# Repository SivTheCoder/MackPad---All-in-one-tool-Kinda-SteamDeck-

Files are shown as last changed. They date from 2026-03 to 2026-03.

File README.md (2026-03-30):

# MackPad — All-in-One Macro Controller  
### By Sivansh Gupta  

---

##  Overview  
**MackPad** is a compact, high-efficiency macropad built to maximize functionality within minimal hardware constraints. Powered by the **Seeeduino XIAO ESP32-S3**, it leverages nearly every available GPIO pin to deliver a rich, customizable user experience.

Designed for **developers, creators, and productivity enthusiasts**, MackPad combines tactile input, visual feedback, and programmable workflows into a single portable device.

---

##  Project Showcase  

### Full Assembly (PCB + Case)
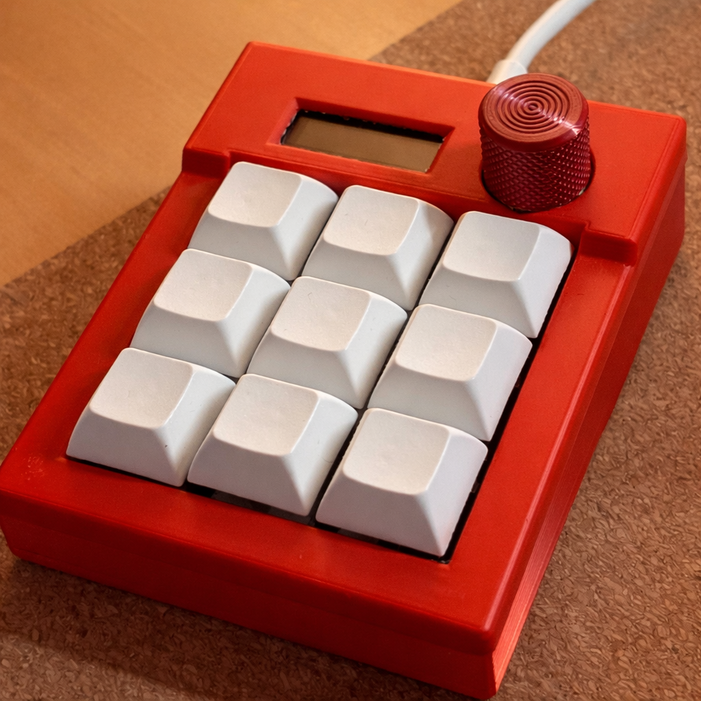
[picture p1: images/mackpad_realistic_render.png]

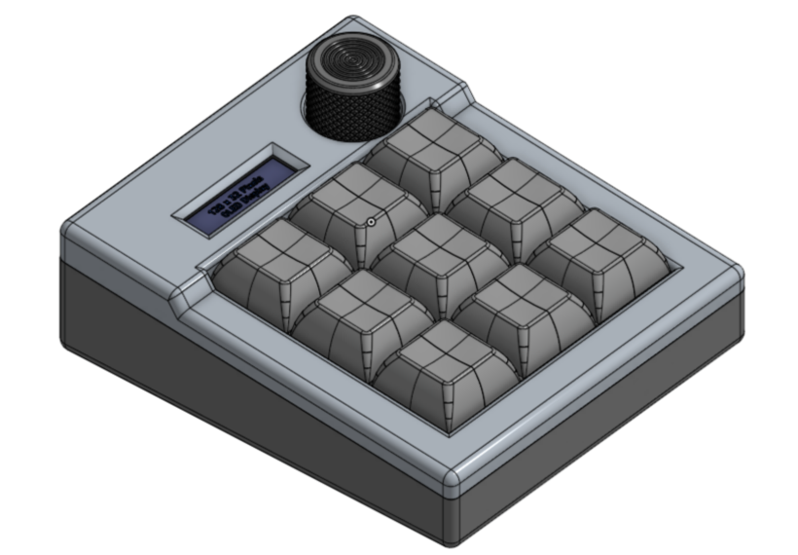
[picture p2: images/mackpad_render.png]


### PCB Design  
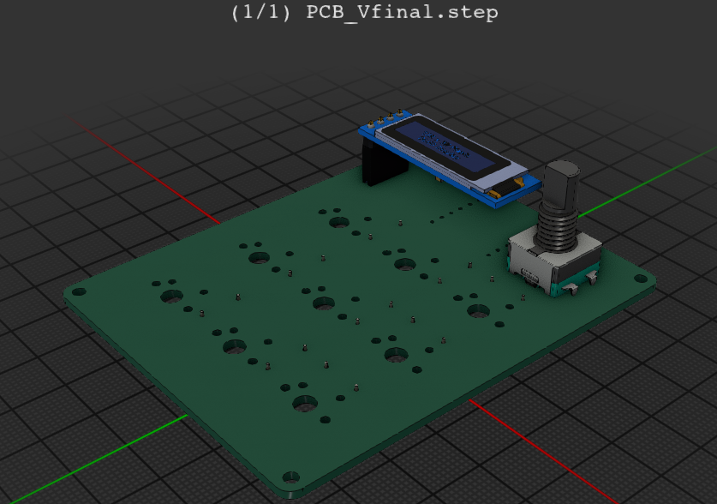
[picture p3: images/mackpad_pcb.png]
PCB


### Different Components  
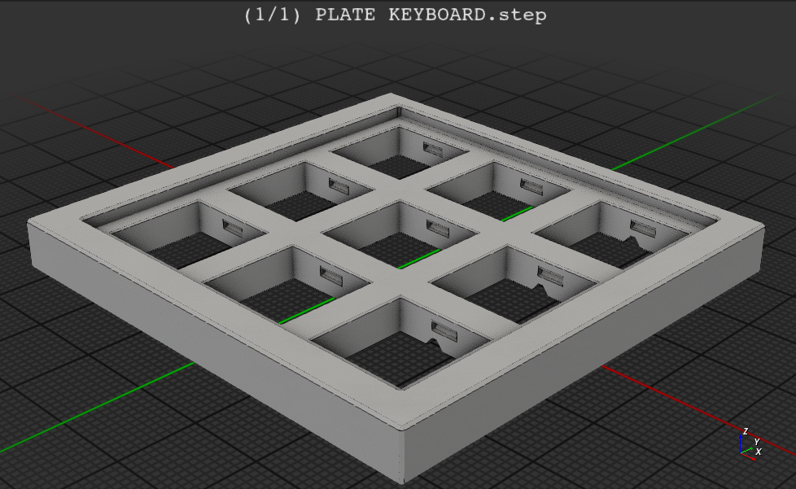
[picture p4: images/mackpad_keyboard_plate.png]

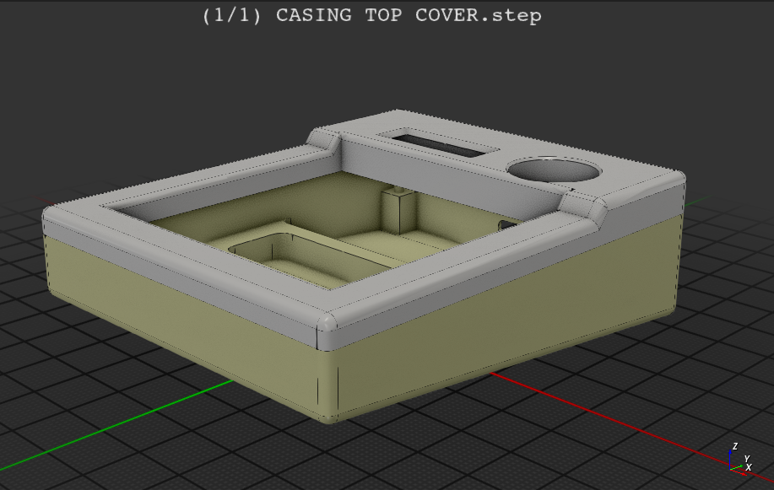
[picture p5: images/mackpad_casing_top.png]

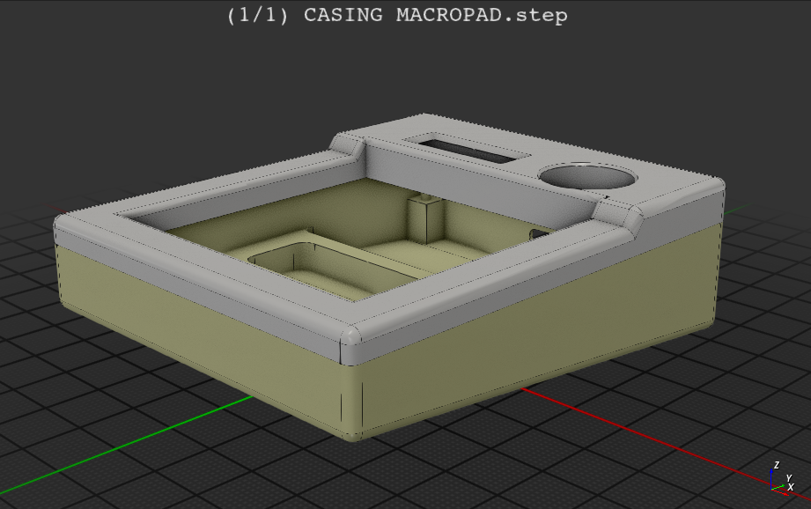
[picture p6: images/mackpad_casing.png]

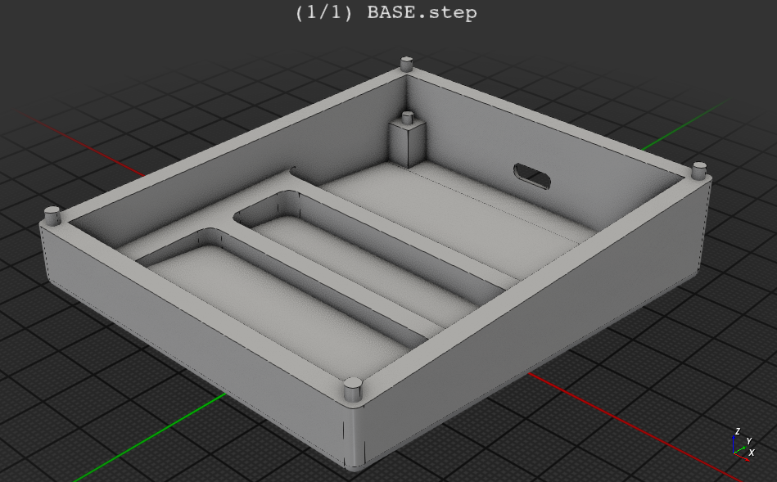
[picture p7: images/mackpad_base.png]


##  Key Features  

- 3×3 NKRO Mechanical Keypad  
- Rotary Encoder with Push Functionality  
- 0.91" OLED Display (Real-time UI Feedback)  
- Neopixel RGB Backlighting  
- Hot-swappable Switch Support  
- Fully Programmable via KMK Firmware  
- Compact and Efficient Embedded Design  

---

##  Motivation  

MackPad began as a simple rotary encoder-based volume controller. It evolved into a fully-featured macropad focused on:

- Speeding up workflows  
- Reducing repetitive actions  
- Providing intuitive visual feedback  
- Maximizing functionality within hardware constraints  

---

##  Hardware Architecture  

- **Microcontroller:** Seeeduino XIAO ESP32-S3  
- **Input System:** 3×3 matrix with diodes (NKRO support)  
- **Rotary Encoder:** Analog-based custom decoding  
- **Display:** SSD1306 OLED (I2C, 128×32)  
- **Lighting:** WS2812 Neopixels  
- **Switches:** MX-style (hot-swappable with Kailh sockets)  

---

##  Firmware  

- Built using **KMK Firmware (CircuitPython)**  
- Features include:  
  - Custom keymaps and macros  
  - OLED UI (layer status, icons, system info)  
  - Rotary encoder multi-function control  
  - Neopixel-based visual feedback  
  - Custom key objects and advanced macro handling  

---

##  Usage  

### Setup  

1. Flash CircuitPython firmware onto the XIAO ESP32-S3  
2. Copy the following to the device:  
   - `code.py`  
   - Required KMK libraries  
   - Display assets (icons/images)  
3. Reboot the device  

---

### Customization  

All customization is handled inside `code.py`:

- Key mappings  
- Macros and shortcuts  
- RGB lighting behavior  
- OLED display output  

---

##  Bill of Materials (BOM)  

| Qty | Component | Notes | USD | INR |
|-----|---|---|---|---|
| 1 | Seeeduino XIAO ESP32-S3 | Microcontroller | $6.00 | ₹500  |
| 9 | MX-style switches | Mechanical switches | $4.50 | ₹375  |
| 9 | 1N4148 diodes | Matrix diodes | $0.90 | ₹75 |
| 1 | SSD1306 OLED (0.91", 128x32) | Display | $3.00 | ₹250  |
| 9 | DSA keycaps | Keycaps | $5.00 | ₹400  |
| 1 | Female header (1x4) | Display mount | $0.50 | ₹40 |
| 1 | EC11 rotary encoder | Input control | $1.50 | ₹120  |
| 3 | Resistors (10k, 47k, 100k) | Voltage divider | $0.30 | ₹30 |
| 9 | Kailh hot-swap sockets | Switch mounting | $6.00 | ₹500  |

### Estimated Total  
- **USD:** ~$27.70  
- **INR:** ~₹2,290  

*Prices may vary depending on supplier.*

---

##  Future Improvements  

### Advanced RGB System  
- Per-key RGB lighting  
- Layer-based color profiles  
- Reactive lighting effects  

### Touch Input Integration  
- Capacitive touch gestures  
- Swipe and tap controls  
- Hybrid input system  

### Wireless Capability  
- Bluetooth connectivity  
- Battery-powered operation  

### Enhanced UI  
- Animated OLED interface  
- Menu-based navigation  
- Dynamic macro previews  

---

##  Project Highlights  

- Efficient use of limited GPIO resources  
- Custom analog decoding for rotary encoder  
- Integration of hardware + firmware + UI design  
- Fully functional productivity tool  

---

### Custom Python-Based Companion Software (Steam Deck Integration)

- Development of a dedicated Python-based companion application designed to run alongside MackPad  
- Enables deep integration with devices like the Steam Deck or PC environments for advanced task execution  
- Supports bidirectional communication between MackPad and the host system (e.g., via Bluetooth/Wi-Fi/USB)  
- Allows dynamic macro triggering based on system context (active app, game state, or workflow)  
- Provides a customizable UI/dashboard for real-time control, monitoring, and macro management  
- Transforms MackPad from a standalone macropad into a hybrid hardware-software control system  
- Unlocks capabilities beyond traditional hackpads, including system-level automation, scripting, and adaptive workflows  

---

##  License  

This project is open-source and available under the MIT License.

---

##  Acknowledgements  

- KMK Firmware Community  
- Good people of Hack Club

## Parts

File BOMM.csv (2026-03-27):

Qty | Item | Notes
1 | SEEEDUINO XIAO ESP32-S3 | Microcontroller board
9 | MX-style switches | 5-pin preferred
9 | 1N4148 through-hole diodes | For switch matrix
1 | SSD1306 128x32 OLED 0.91" | I2C display
9 | Blank DSA keycaps
1 | 1x4 2.54mm female header | For raising display height
1 | EC11 rotary encoder
1 | 10kΩ metal film resistor | Part of voltage divider
1 | 47kΩ metal film resistor | Voltage divider
1 | 100kΩ metal film resistor | Voltage divider
9 | Kailh MX hot-swap sockets | For hot-swappable switches

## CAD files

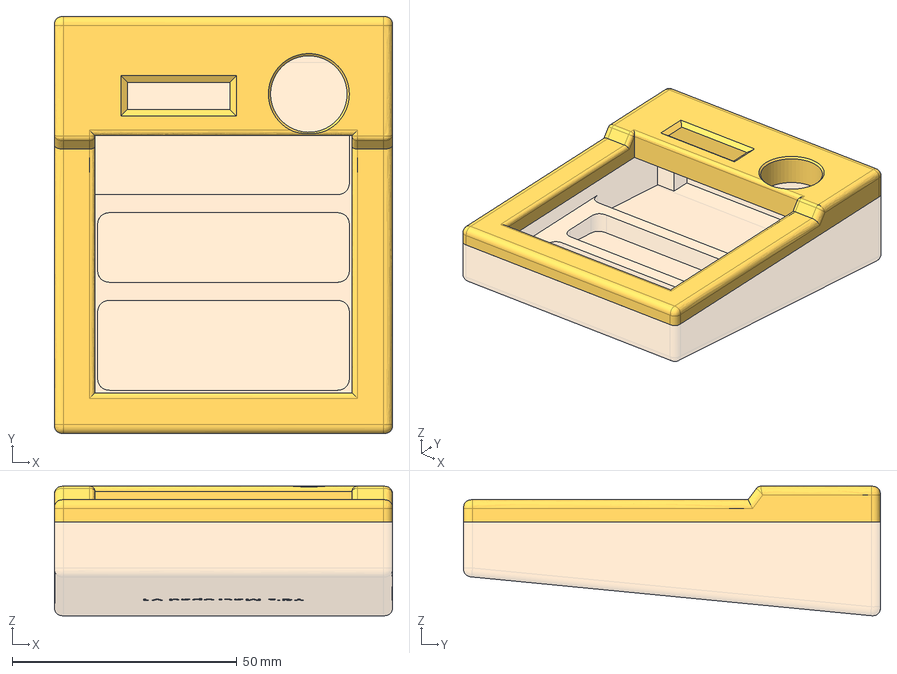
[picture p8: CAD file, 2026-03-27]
CAD Files_Vfinal/CASING TOP COVER.step
75.2 x 92.7 x 28.8 mm

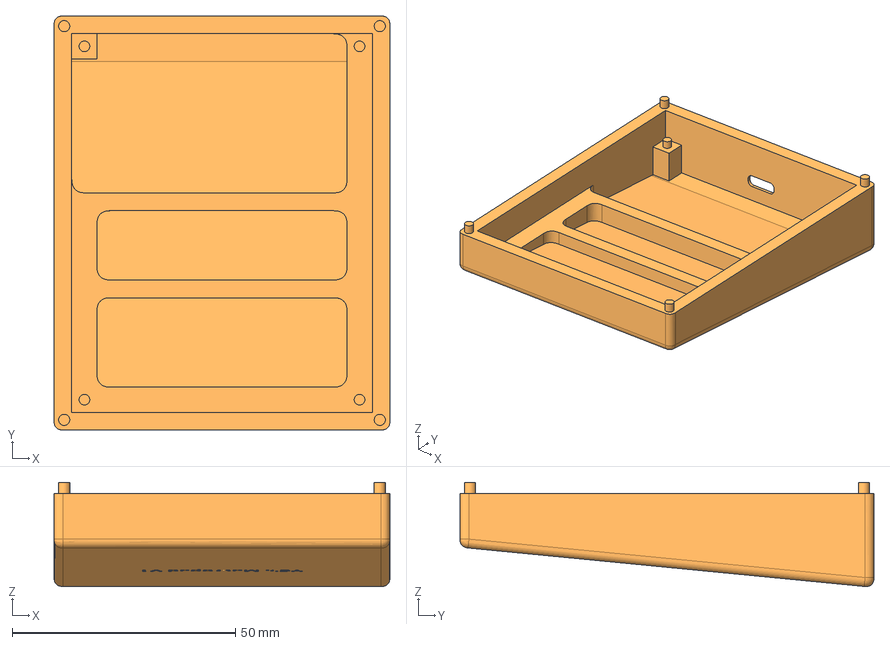
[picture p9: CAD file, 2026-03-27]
CAD Files_Vfinal/BASE.step
75.2 x 92.7 x 23.3 mm

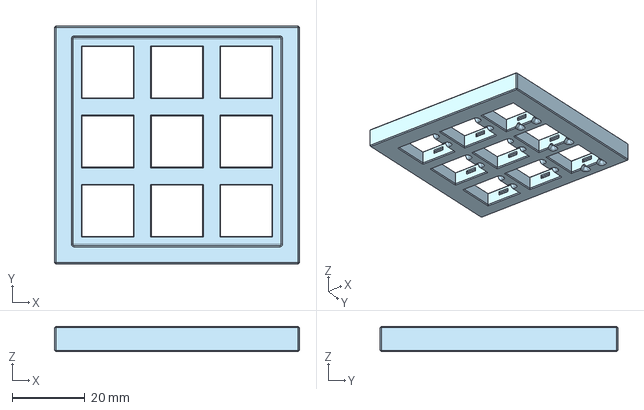
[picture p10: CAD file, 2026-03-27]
CAD Files_Vfinal/PLATE KEYBOARD.step
67.4 x 65.4 x 7.00 mm

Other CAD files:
CAD Files_Vfinal/CASING MACROPAD.step

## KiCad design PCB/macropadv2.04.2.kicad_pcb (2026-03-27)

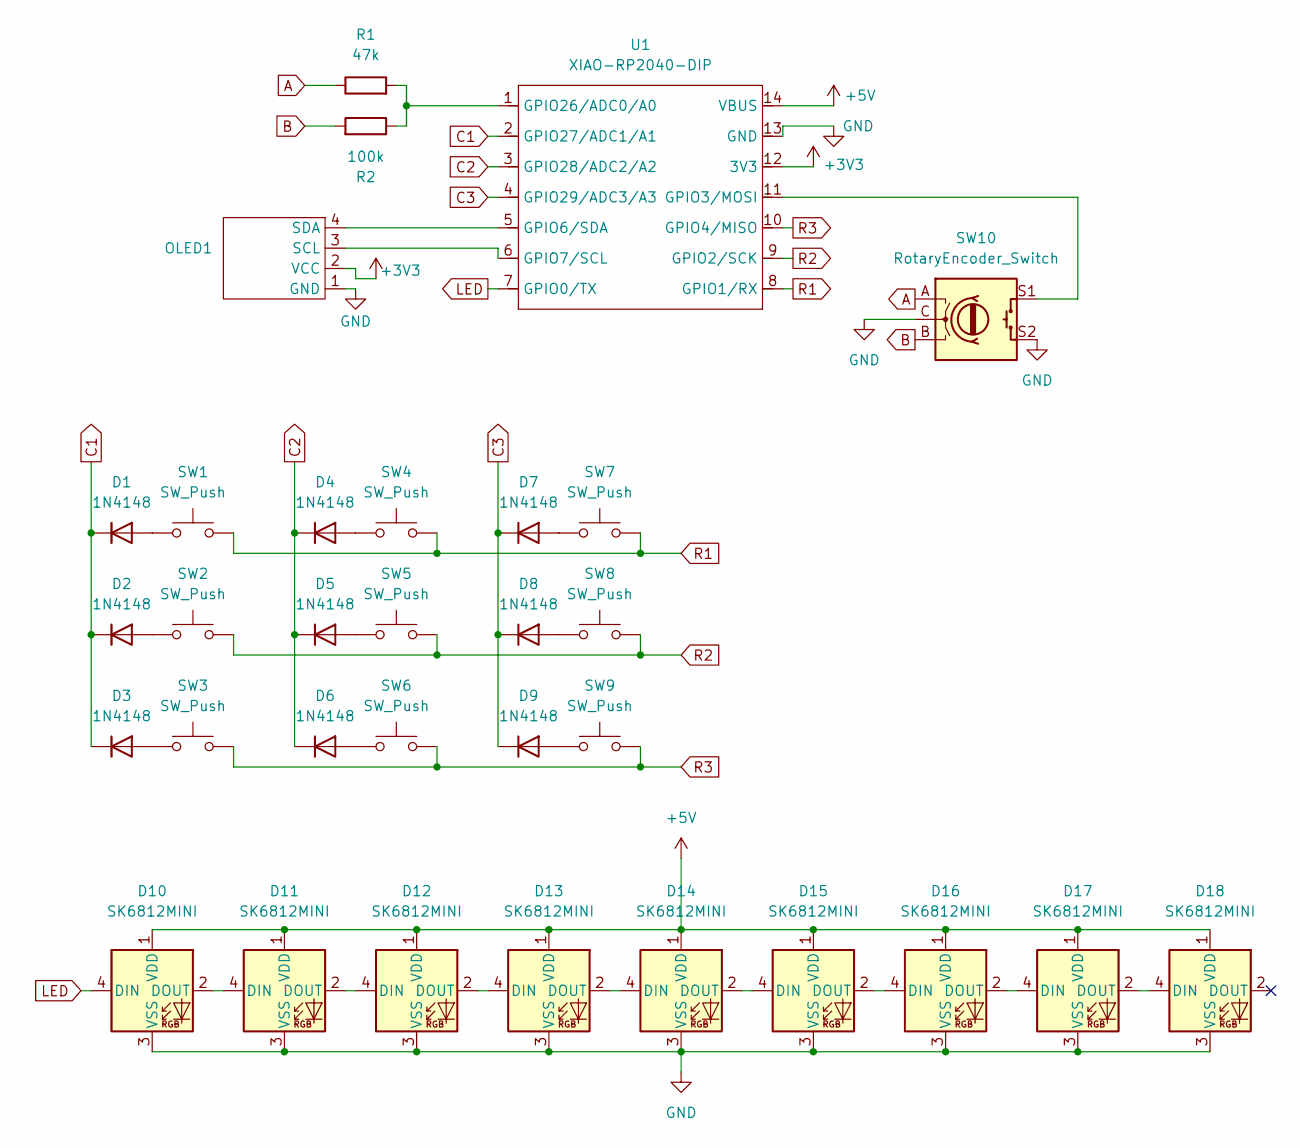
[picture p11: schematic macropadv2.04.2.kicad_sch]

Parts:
D1, D2, D3, D4, D5, D6, D7, D8, D9: 1N4148; D_DO-35_SOD27_P7.62mm_Horizontal
D10, D11, D12, D13, D14, D15, D16, D17, D18: SK6812MINI; MX_SK6812MINI-E_REV
OLED1: SSD1306-0.91-OLED-4pin-128x32
R1: 47k; R_Axial_DIN0207_L6.3mm_D2.5mm_P10.16mm_Horizontal
R2: 100k; R_Axial_DIN0207_L6.3mm_D2.5mm_P10.16mm_Horizontal
SW1, SW2, SW3, SW4, SW5, SW6, SW7, SW8, SW9: SW_Push; MX-Hotswap-1U
SW10: RotaryEncoder_Switch; RotaryEncoder_Alps_EC11E-Switch_Vertical_H20mm
U1: XIAO-RP2040-DIP

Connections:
+3V3: OLED1.2 (VCC), U1.12 (3V3)
+5V: D10.1 (VDD), D11.1 (VDD), D12.1 (VDD), D13.1 (VDD), D14.1 (VDD), D15.1 (VDD), D16.1 (VDD), D17.1 (VDD), D18.1 (VDD), U1.14 (VBUS)
A: R1.1, SW10.A
B: R2.2, SW10.B
C1: D1.1 (K), D2.1 (K), D3.1 (K), U1.2 (GPIO27/ADC1/A1)
C2: D4.1 (K), D5.1 (K), D6.1 (K), U1.3 (GPIO28/ADC2/A2)
C3: D7.1 (K), D8.1 (K), D9.1 (K), U1.4 (GPIO29/ADC3/A3)
GND: D10.3 (VSS), D11.3 (VSS), D12.3 (VSS), D13.3 (VSS), D14.3 (VSS), D15.3 (VSS), D16.3 (VSS), D17.3 (VSS), D18.3 (VSS), OLED1.1 (GND), SW10.C, SW10.S2, U1.13 (GND)
LED: D10.4 (DIN), U1.7 (GPIO0/TX)
unnamed: D1.2 (A), SW1.2
unnamed: D2.2 (A), SW2.2
unnamed: D3.2 (A), SW3.2
unnamed: D4.2 (A), SW4.2
unnamed: D5.2 (A), SW5.2
unnamed: D6.2 (A), SW6.2
unnamed: D7.2 (A), SW7.2
unnamed: D8.2 (A), SW8.2
unnamed: D9.2 (A), SW9.2
unnamed: D10.2 (DOUT), D11.4 (DIN)
unnamed: D11.2 (DOUT), D12.4 (DIN)
unnamed: D12.2 (DOUT), D13.4 (DIN)
unnamed: D13.2 (DOUT), D14.4 (DIN)
unnamed: D14.2 (DOUT), D15.4 (DIN)
unnamed: D15.2 (DOUT), D16.4 (DIN)
unnamed: D16.2 (DOUT), D17.4 (DIN)
unnamed: D17.2 (DOUT), D18.4 (DIN)
unnamed: OLED1.3 (SCL), U1.6 (GPIO7/SCL)
unnamed: OLED1.4 (SDA), U1.5 (GPIO6/SDA)
unnamed: SW10.S1, U1.11 (GPIO3/MOSI)
unnamed: R1.2, R2.1, U1.1 (GPIO26/ADC0/A0)
R1: SW1.1, SW4.1, SW7.1, U1.8 (GPIO1/RX)
R2: SW2.1, SW5.1, SW8.1, U1.9 (GPIO2/SCK)
R3: SW3.1, SW6.1, SW9.1, U1.10 (GPIO4/MISO)

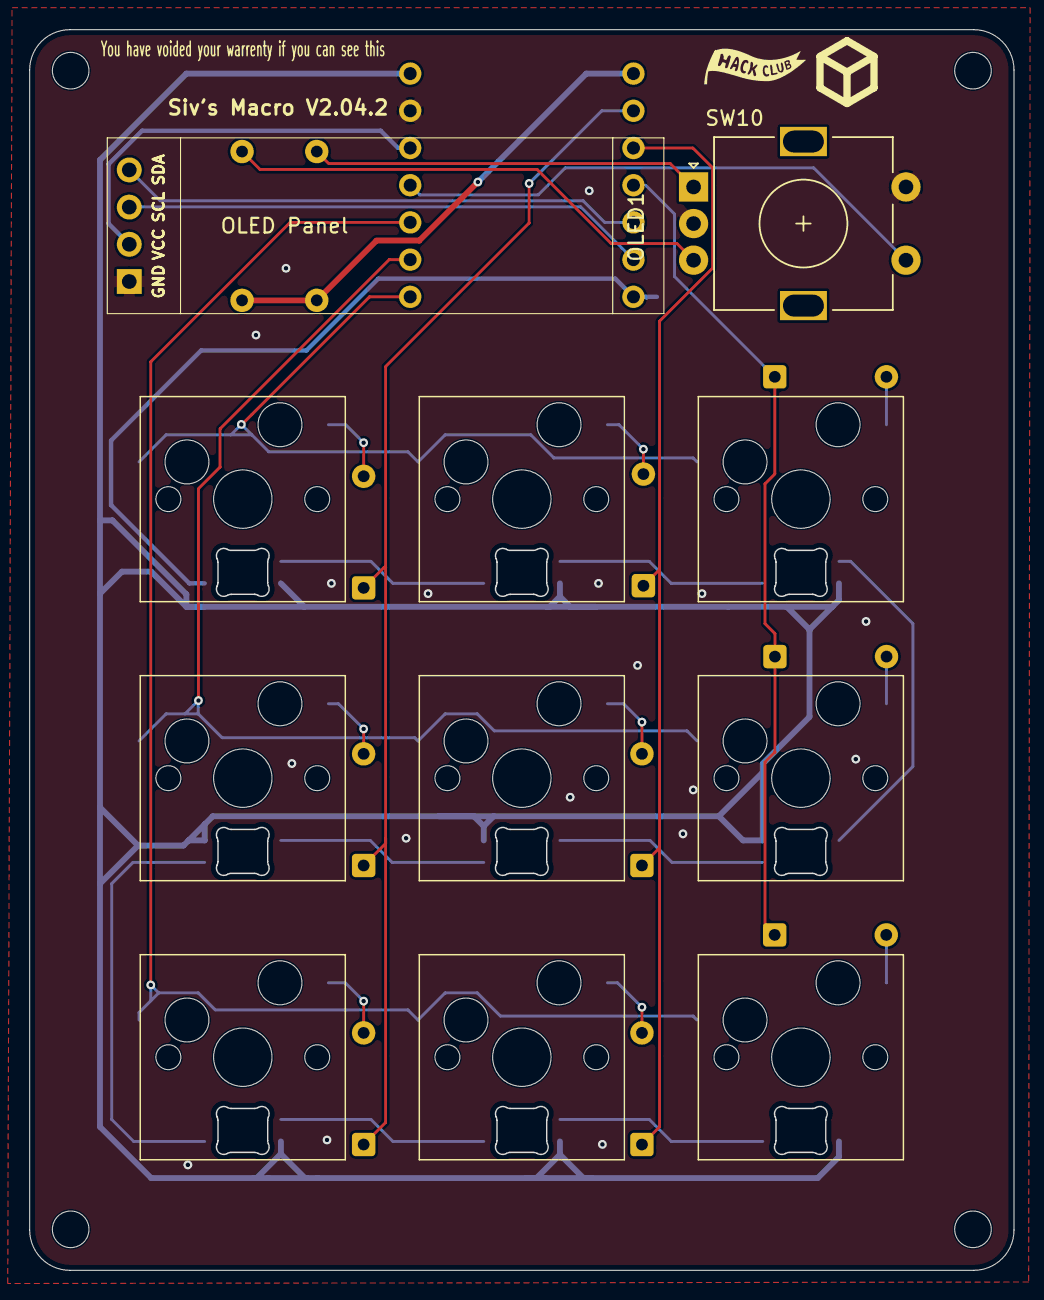
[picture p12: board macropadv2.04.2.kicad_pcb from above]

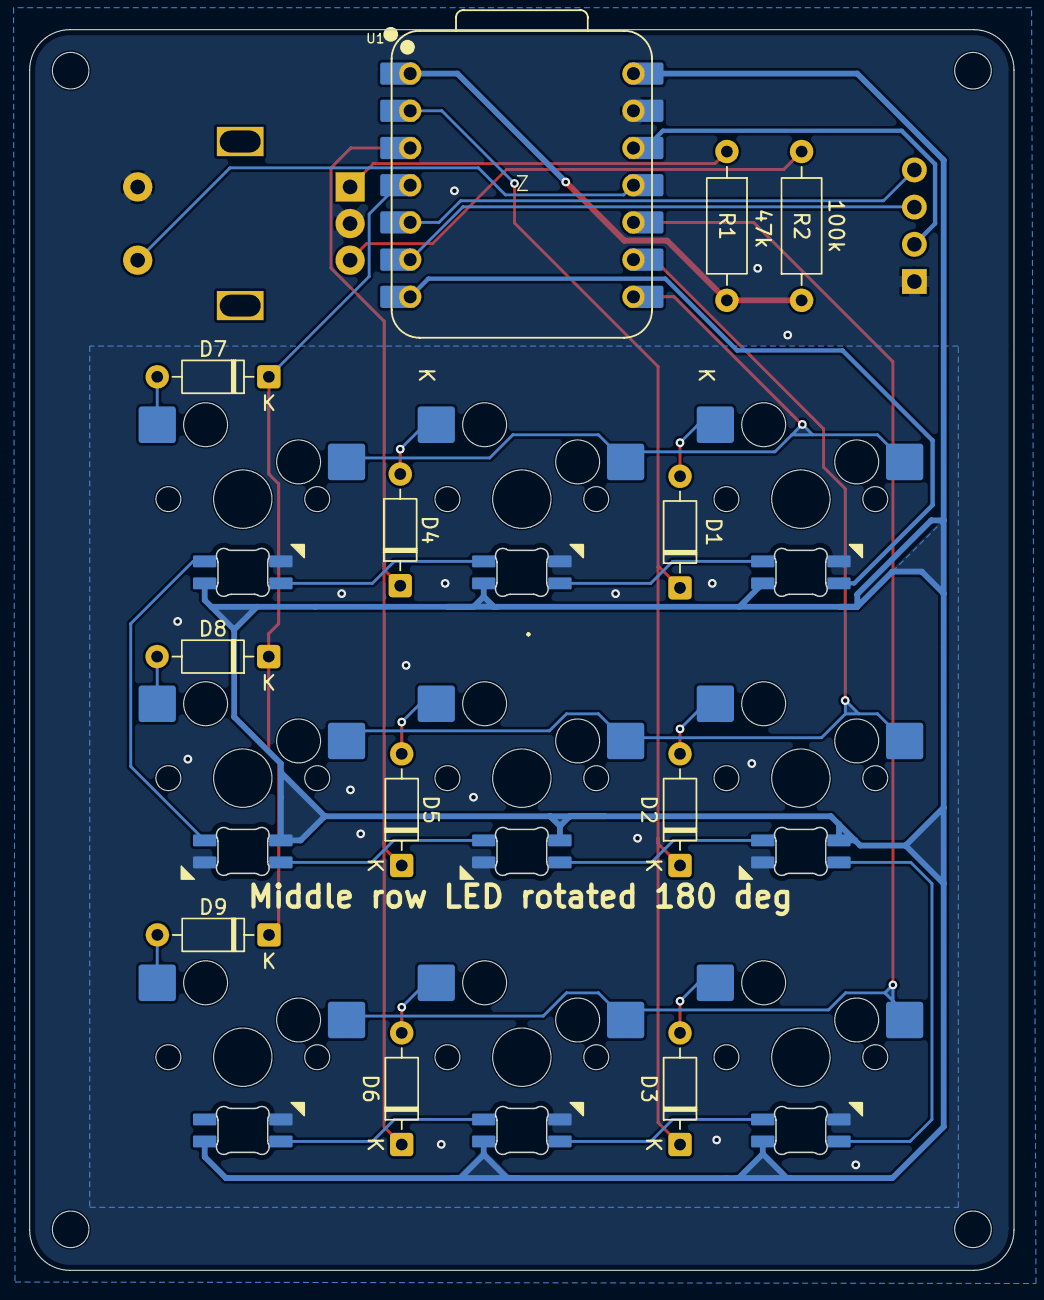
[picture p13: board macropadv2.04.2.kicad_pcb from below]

Board: 2 copper layers, 67.2 x 84.7 mm, 32 parts (21 on the bottom side), 33 nets.

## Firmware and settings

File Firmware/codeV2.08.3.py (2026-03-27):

import board
import analogio
import busio, time

from kmk.kmk_keyboard import KMKKeyboard
from kmk.keys import KC, Key
from kmk.scanners import DiodeOrientation
from kmk.scanners.keypad import MatrixScanner, KeysScanner
from kmk.modules import Module
from kmk.modules.layers import Layers
from kmk.modules.macros import Delay, Press, Release, Tap, Macros
from kmk.modules.holdtap import HoldTap

from kmk.extensions.RGB import RGB
from kmk.extensions.rgb import AnimationModes
from kmk.extensions.media_keys import MediaKeys
from kmk.extensions.display import Display, TextEntry, ImageEntry
from kmk.extensions.display.ssd1306 import SSD1306


# =========================
# ANALOG ENCODER MODULE
# =========================

class AnalogEncoder(Module):
    def __init__(self, analog_pin, adc_thresholds, key_clockwise, key_counterclockwise):
        self.analog_pin = analog_pin
        self.thresholds = adc_thresholds
        self.key_cw = key_clockwise
        self.key_ccw = key_counterclockwise

        self.adc_input = None
        self.previous_state = None

    def during_bootup(self, keyboard):
        self.adc_input = analogio.AnalogIn(self.analog_pin)

    def before_matrix_scan(self, keyboard):
        adc_value = self.adc_input.value
        current_state = self._determine_state(adc_value)

        if self.previous_state is None:
            print("Initial state:", current_state, "ADC:", adc_value)

        elif current_state != self.previous_state:
            print("STATE CHANGE:", self.previous_state, "→", current_state, "ADC:", adc_value)

            if self.previous_state == 3:
                if current_state == 2:
                    keyboard.tap_key(self.key_ccw)
                elif current_state == 1:
                    keyboard.tap_key(self.key_cw)

        self.previous_state = current_state
        return keyboard

    def _determine_state(self, adc_value):
        for index, threshold in enumerate(self.thresholds):
            if adc_value < threshold:
                return index
        return len(self.thresholds)

    def after_matrix_scan(self, keyboard):
        return keyboard


# =========================
# KEYBOARD CLASS
# =========================

class MackPad(KMKKeyboard):
    def __init__(self):
        super().__init__()

        self.matrix = [
            MatrixScanner(
                column_pins=(board.D1, board.D2, board.D3),
                row_pins=(board.D7, board.D8, board.D9),
                columns_to_anodes=DiodeOrientation.ROW2COL
            ),
            KeysScanner(
                pins=[board.D10],
                value_when_pressed=False,
            ),
        ]


keyboard = MackPad()
keyboard.extensions.append(MediaKeys())


# =========================
# ENCODER SETUP
# =========================

encoder_module = AnalogEncoder(
    analog_pin=board.A0,
    adc_thresholds=[1270, 10000, 40000],
    key_clockwise=KC.VOLU,
    key_counterclockwise=KC.VOLD,
)

keyboard.modules.append(encoder_module)


# =========================
# RGB CONTROL
# =========================

rgb_enabled = True


class LayerBasedRGB(RGB):
    def on_layer_change(self, layer_index):
        if rgb_enabled:
            if layer_index == 0:
                self.set_hsv_fill(79, self.sat_default, self.val_default)
            elif layer_index == 1:
                self.set_hsv_fill(170, self.sat_default, self.val_default)
            elif layer_index == 2:
                self.set_hsv_fill(20, self.sat_default, self.val_default)
            elif layer_index == 3:
                self.set_hsv_fill(180, self.sat_default, self.val_default)
            elif layer_index == 4:
                self.set_hsv_fill(225, self.sat_default, self.val_default)
            elif layer_index == 5:
                self.set_hsv_fill(0, 0, self.val_default)
        else:
            self.set_hsv_fill(0, 0, 0)

        if layer_index == 6:
            self.set_hsv_fill(0, 0, 0)
            self.set_hsv(0, self.sat_default, 100 if rgb_enabled else 40, 8)
            self.set_hsv(0, self.sat_default, 30 if rgb_enabled else 10, 3)

        self.show()

    def on_layer_change_flash(self):
        if rgb_enabled:
            self.set_hsv_fill(0, 255, 15)
        else:
            self.set_hsv_fill(0, 255, 10)
        self.show()


rgb_controller = LayerBasedRGB(
    pixel_pin=board.D6,
    num_pixels=9,
    hue_default=79,
    sat_default=255,
    val_default=67,
)

keyboard.extensions.append(rgb_controller)


# =========================
# LAYER MANAGEMENT
# =========================

class RGBLayerController(Layers):
    def __init__(self):
        super().__init__()
        self.active_layer_index = 0

    def activate_layer(self, keyboard, layer, idx=None):
        super().activate_layer(keyboard, layer, idx)

        if layer != 6:
            rgb_controller.on_layer_change_flash()
            time.sleep(0.15)
            self.active_layer_index = layer

        rgb_controller.on_layer_change(layer)

    def deactivate_layer(self, keyboard, layer):
        super().deactivate_layer(keyboard, layer)
        rgb_controller.on_layer_change_flash()
        rgb_controller.on_layer_change(keyboard.active_layers[0])


layer_controller = RGBLayerController()
keyboard.modules.append(layer_controller)


# =========================
# MACROS
# =========================

macro_module = Macros()
keyboard.modules.append(macro_module)


MACRO_SPAM = KC.MACRO("chargoggagoggmanchauggagoggchaubunagungamaugg")

MACRO_NUMBERS = KC.MACRO(
    " 000000000011111111112222222222333333333344444444445555555555666666666677777777778888888888999999999900000000 "
)

MUTE_DISCORD = KC.MACRO(
    Press(KC.RALT), Press(KC.RSHIFT), Tap(KC.M),
    Release(KC.RALT), Release(KC.RSHIFT)
)

DEAFEN_DISCORD = KC.MACRO(
    Press(KC.RALT), Press(KC.RSHIFT), Tap(KC.D),
    Release(KC.RALT), Release(KC.RSHIFT)
)


# =========================
# HOLD-TAP SETUP
# =========================

hold_tap_module = HoldTap()
keyboard.modules.append(hold_tap_module)


# =========================
# ROTARY BUTTON LOGIC
# =========================

rotary_mode_mute = True

icon_sound = "sound16.bmp"
icon_play = "play16.bmp"

icon_display = ImageEntry(image=icon_sound, x=112)


class EncoderPressKey(Key):
    def __init__(self, primary_key, secondary_key):
        self.primary = primary_key
        self.secondary = secondary_key

    def on_press(self, keyboard, coord_int=None):
        keyboard.add_key(self.primary if rotary_mode_mute else self.secondary)

    def on_release(self, keyboard, coord_int=None):
        keyboard.remove_key(self.primary if rotary_mode_mute else self.secondary)


class EncoderModeToggle(Key):
    def on_press(self, keyboard, coord_int=None):
        global rotary_mode_mute
        rotary_mode_mute = not rotary_mode_mute

        icon_display.setImage(icon_sound if rotary_mode_mute else icon_play)
        display.render(layer_controller.active_layer_index)


class RGBToggle(Key):
    def on_press(self, keyboard, coord_int=None):
        global rgb_enabled
        rgb_enabled = not rgb_enabled


encoder_tap_key = EncoderPressKey(KC.MUTE, KC.MPLY)
encoder_hold_key = EncoderModeToggle()
rgb_toggle_key = RGBToggle()

ENCODER_KEY = KC.HT(encoder_tap_key, encoder_hold_key, prefer_hold=True, tap_time=300)
MODE_KEY = KC.HT(KC.ENTER, KC.MO(6), prefer_hold=True, tap_time=180)


# =========================
# DISPLAY
# =========================

i2c = busio.I2C(board.SCL, board.SDA)

oled_driver = SSD1306(i2c=i2c)

display = Display(
    display=oled_driver,
    width=128,
    height=32,
    brightness=0.4,
)

display.entries = [
    TextEntry(text="MackPad v1.0", x=0, y=0),
    icon_display,
    TextEntry(text="Default", x=0, y=12, layer=0),
    TextEntry(text="Speedrun", x=0, y=12, layer=1),
    TextEntry(text="Editing", x=0, y=12, layer=2),
    TextEntry(text="Custom 1", x=0, y=12, layer=3),
    TextEntry(text="Custom 2", x=0, y=12, layer=4),
    TextEntry(text="Numpad", x=0, y=12, layer=5),
    TextEntry(text="Mode Swap", x=0, y=12, layer=6),
]

keyboard.extensions.append(display)


# =========================
# KEYMAP
# =========================

keyboard.keymap = [
    [
        MACRO_SPAM, MACRO_NUMBERS, KC.SPACE,
        KC.VOLD, KC.MPLY, KC.VOLU,
        MUTE_DISCORD, DEAFEN_DISCORD, MODE_KEY,
        ENCODER_KEY
    ],
]


# =========================
# START
# =========================

if __name__ == "__main__":
    keyboard.go()

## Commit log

2026-03-27 Remove hardware design and enclosure details from README
    Removed hardware design and enclosure sections from README.
2026-03-27 Update microcontroller from RP2040 to ESP32 S3
